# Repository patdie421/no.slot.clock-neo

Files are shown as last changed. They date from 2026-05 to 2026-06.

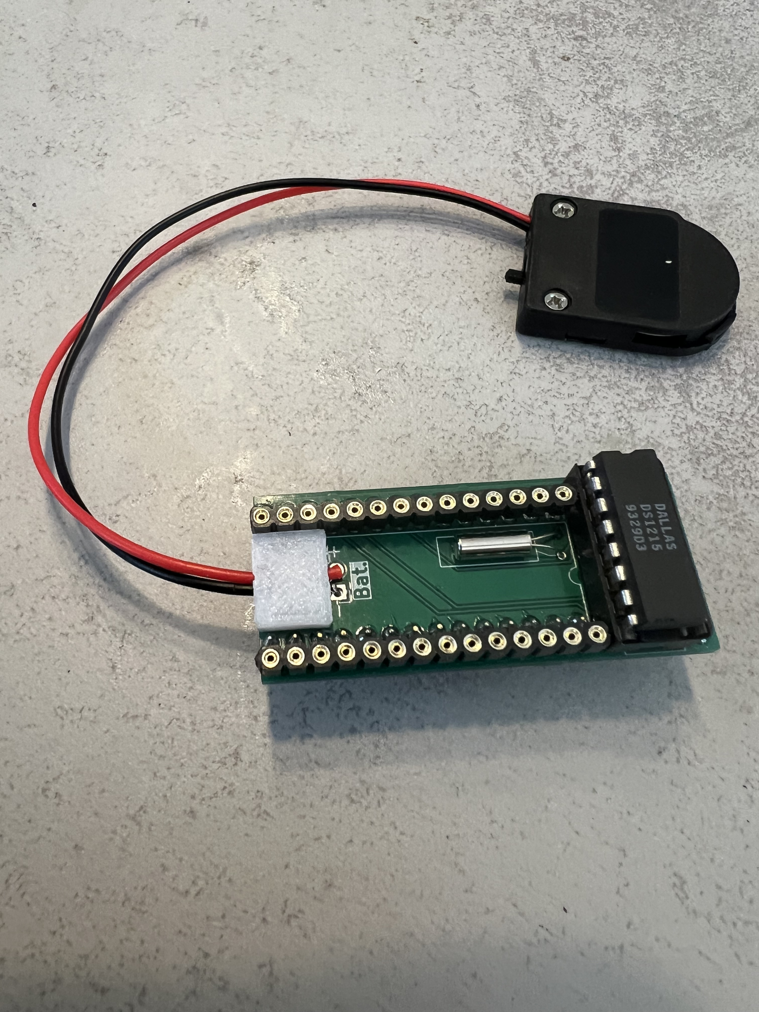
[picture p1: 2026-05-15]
IMG_3988.jpeg

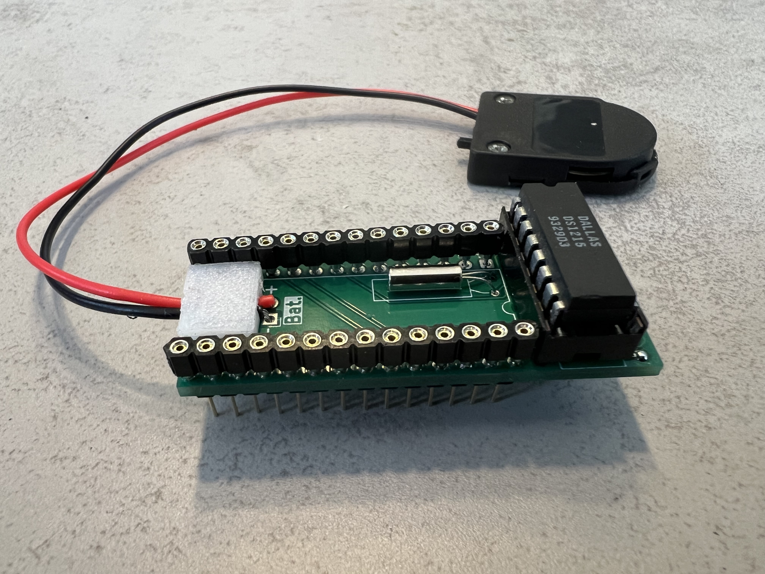
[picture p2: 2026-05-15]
IMG_3989.jpeg

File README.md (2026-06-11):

# no.slot.clock-neo

v2.1 Tested in an Apple IIe (europa motherboard) and works fine. Other version will be tested soon.  

Use the DS1215 DIP chip and readily available through-hole components  at a reasonable price (except for the DS1215 :-( ).  

This PCB is is functionally equivalent to the DS1216 E/F (cf. https://github.com/patdie421/no.slot.clock-neo/blob/main/resources/DS1216.PDF).  

Modern driver available in this repository : https://github.com/a2stuff/prodos-drivers  

other resources :  

* Reactive micro "no slot clock" : https://wiki.reactivemicro.com/No-Slot_Clock ($$$)  
* An other PCB with smd components : https://www.xpmtl.net/wordpress/apple-ii/no-slot-clock/  (pcb design not found, but nice job)  
* Original driver source code : https://gist.github.com/mgcaret/ae2860c754fd029d2640107c4fe0bffd  
* Original user manual : https://mirrors.apple2.org.za/Apple%20II%20Documentation%20Project/Chips/SMT%20No-Slot%20Clock/Manuals/No-Slot%20Clock%20-%20Manual.pdf  
* Original software : https://mirrors.apple2.org.za/Apple%20II%20Documentation%20Project/Chips/SMT%20No-Slot%20Clock/Disk%20Images/

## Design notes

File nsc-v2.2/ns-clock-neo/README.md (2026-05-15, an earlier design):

Second release (not tested yet).  

One of the parts is designed for Apple IIe (European) to avoid any conflict with long cards in slot 1 (NSC is too high if using CI sockets for ROM).

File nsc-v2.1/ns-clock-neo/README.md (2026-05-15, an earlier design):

First working release  

Breakable dual circuit board with different ROM orientations. Allows testing of positioning on different types of Apple II.

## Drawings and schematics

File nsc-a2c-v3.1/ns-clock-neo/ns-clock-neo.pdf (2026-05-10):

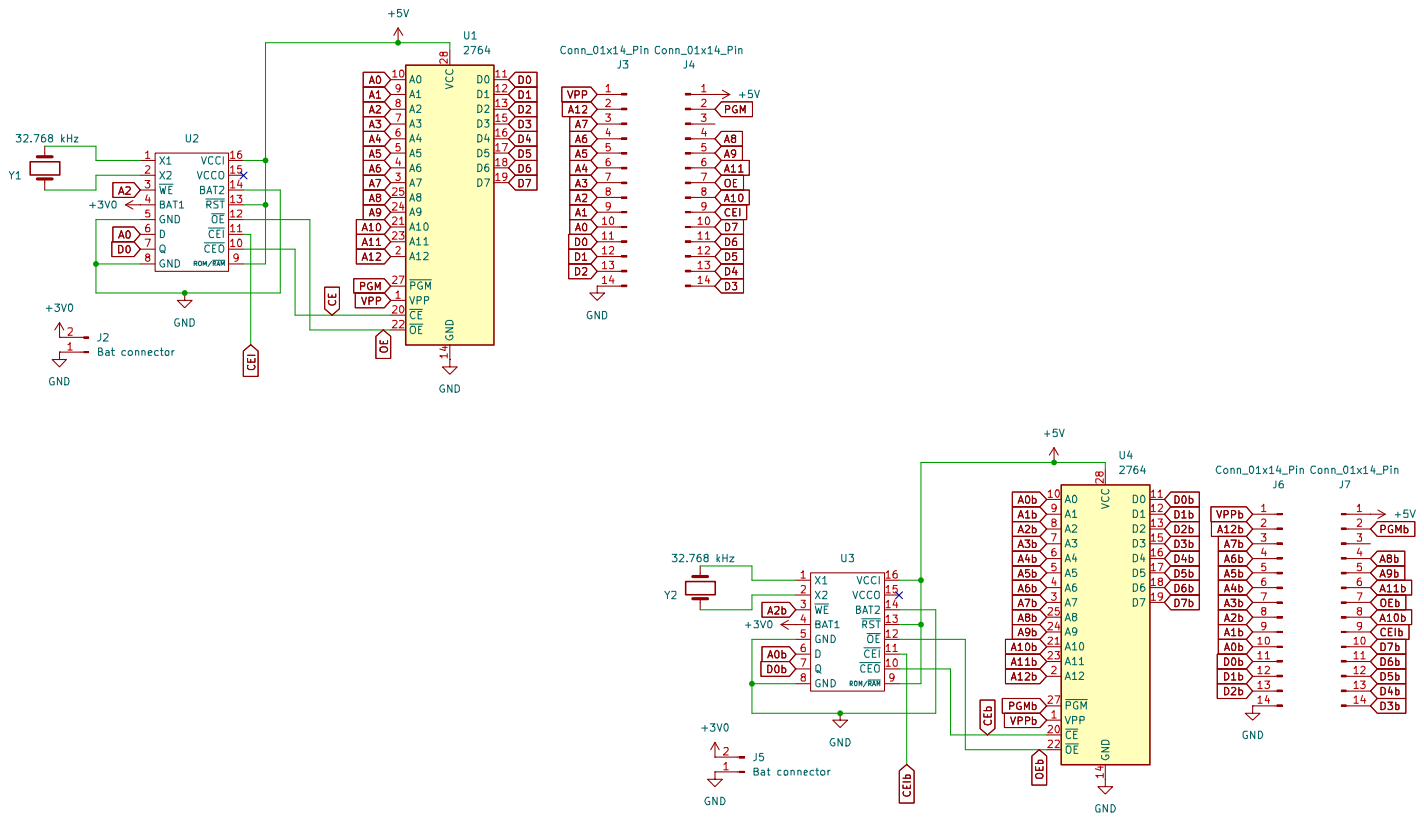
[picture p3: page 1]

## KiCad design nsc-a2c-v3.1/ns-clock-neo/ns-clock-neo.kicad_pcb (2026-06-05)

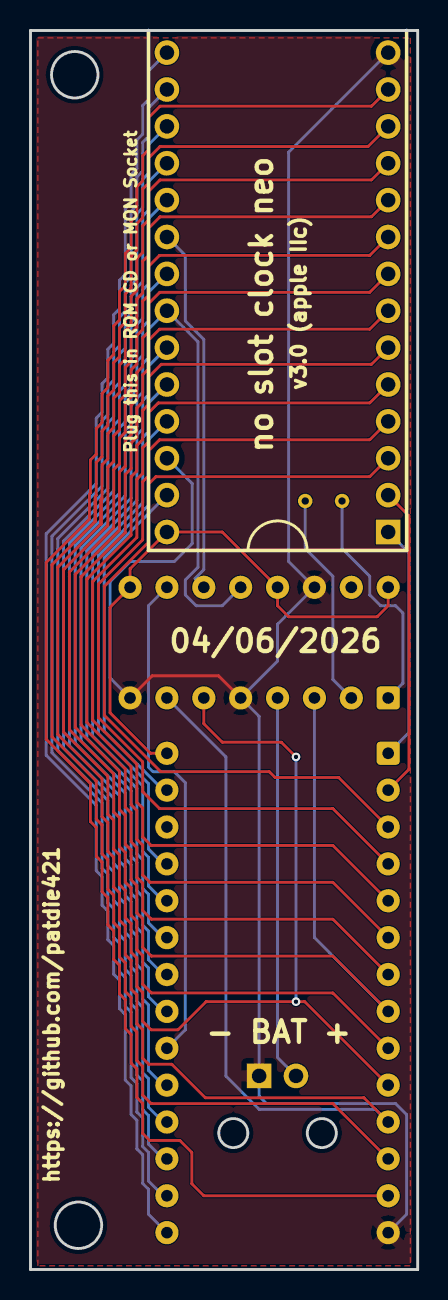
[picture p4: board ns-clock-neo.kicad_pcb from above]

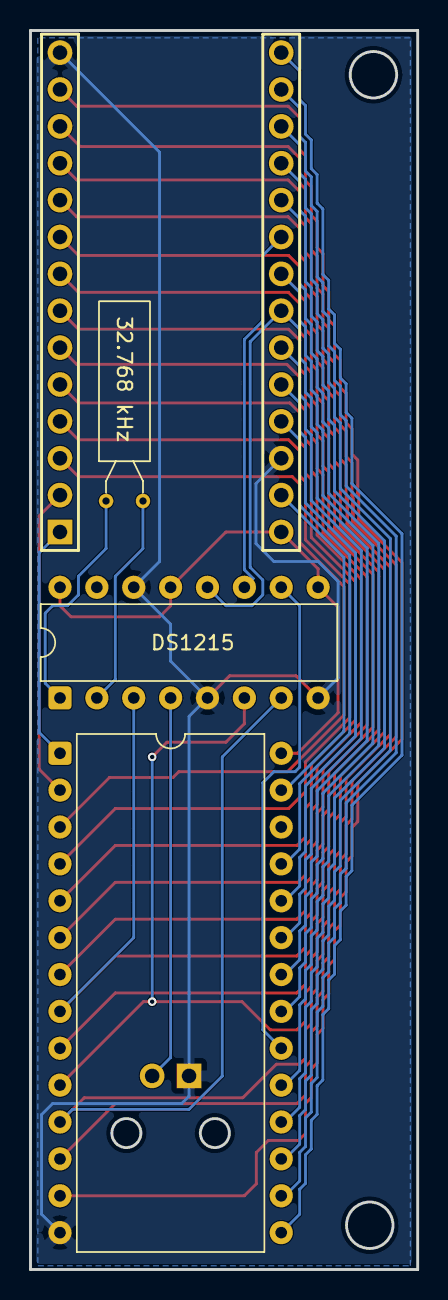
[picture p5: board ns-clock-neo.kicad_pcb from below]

Board: 2 copper layers, 26.7 x 85.3 mm, 6 parts (2 on the bottom side), 31 nets.

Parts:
DS1215: DIP-16_W7.62mm
J2: Bat connector; PinHeader_1x02_P2.54mm_Horizontal
J3, J4: Conn_01x14_Pin; PinHeader_1x14_P2.54mm_Vertical
U1: 2764; DIP-28_W15.24mm
Y1: 32.768 kHz; Crystal_AT310_D3.0mm_L10.0mm_Horizontal

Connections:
+3V0: DS1215.4 (BAT1), J2.2
+5V: DS1215.9 (ROM/~RAM), DS1215.13 (~RST), DS1215.16 (VCCI), J4.1, U1.28 (VCC)
A0: DS1215.6 (D), J3.10, U1.10 (A0)
A1: J3.9, U1.9 (A1)
A2: DS1215.3 (~WE), J3.8, U1.8 (A2)
A3: J3.7, U1.7 (A3)
A4: J3.6, U1.6 (A4)
A5: J3.5, U1.5 (A5)
A6: J3.4, U1.4 (A6)
A7: J3.3, U1.3 (A7)
A8: J4.4, U1.25 (A8)
A9: J4.5, U1.24 (A9)
A10: J4.8, U1.21 (A10)
A11: J4.6, U1.23 (A11)
A12: J3.2, U1.2 (A12)
CE: DS1215.10 (~CEO), U1.20 (~CE)
CEI: DS1215.11 (~CEI), J4.9
D0: DS1215.7 (Q), J3.11, U1.11 (D0)
D1: J3.12, U1.12 (D1)
D2: J3.13, U1.13 (D2)
D3: J4.14, U1.15 (D3)
D4: J4.13, U1.16 (D4)
D5: J4.12, U1.17 (D5)
D6: J4.11, U1.18 (D6)
D7: J4.10, U1.19 (D7)
GND: DS1215.5 (GND), DS1215.8 (GND), DS1215.14 (BAT2), J2.1, J3.14, J4.3, U1.14 (GND)
unnamed: DS1215.1 (X1), Y1.1
unnamed: DS1215.2 (X2), Y1.2
OE: DS1215.12 (~OE), J4.7, U1.22 (~OE)
PGM: J4.2, U1.27 (~PGM)
VPP: J3.1, U1.1 (VPP)

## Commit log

2026-05-10 Add reference to DS1216F and prodos-drivers
2026-05-10 Add driver and resource links to README
